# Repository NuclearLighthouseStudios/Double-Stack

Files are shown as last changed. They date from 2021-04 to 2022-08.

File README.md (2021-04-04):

# Double Stack Distortion

These are the KiCAD schematics and board layout filed for my Double Stack Distortion pedal.  
If you just want the Gerber files or a PDF of the schematic check out the releases tab for downloads.

This PCB should be easily manufacturable with most online PCB houses by just uploading the gerber files.

This board is designed to be used with my Switchboard Pedal IO PCB which you can find [here](https://github.com/NuclearLighthouseStudios/Switchboard).

## BOM

| Reference | Quantity | Value  | Description |
| :--- | ---: | -----: | :--- |
| C1 C7 C8 | 3 | 100n | WIMA MKS2 63V |
| C2 C4 C5 | 3 | 470n | WIMA MKS2 50V |
| C3 C6 C10 | 3 | 1µ | WIMA MKS2 50V |
| C9 | 1 | 1n | WIMA FKP2 63V |
| D1 D2 D3 D4 | 4 | 1N4148 | DO-35 Diode |
| J1 | 1 | | Pin Header, 6 pins, 2.54mm spacing |
| J2 | 1 | | DC Barrel Jack with internal switch |
| Q1 Q2 Q3 Q4 | 4 | BC547B | 0.1A Ic, 45V Vce, Small Signal NPN Transistor, TO-92 |
| R1 R2 R11 R12 | 4 | 1M | Metal film resistor 1%, DIN 0207 |
| R10 | 1 | 390k | Metal film resistor 1%, DIN 0207 |
| R3 R7 R9 R13  | 4 | 10k | Metal film resistor 1%, DIN 0207 |
| R4 | 1 | 4.7k | Metal film resistor 1%, DIN 0207 |
| R5 R8 | 2 | 100k | Metal film resistor 1%, DIN 0207 |
| R6 R14 | 2 | 39k | Metal film resistor 1%, DIN 0207 |
| RV1 RV2 | 2 | 100k | Alps RK09K1130C94 Potentiometer |

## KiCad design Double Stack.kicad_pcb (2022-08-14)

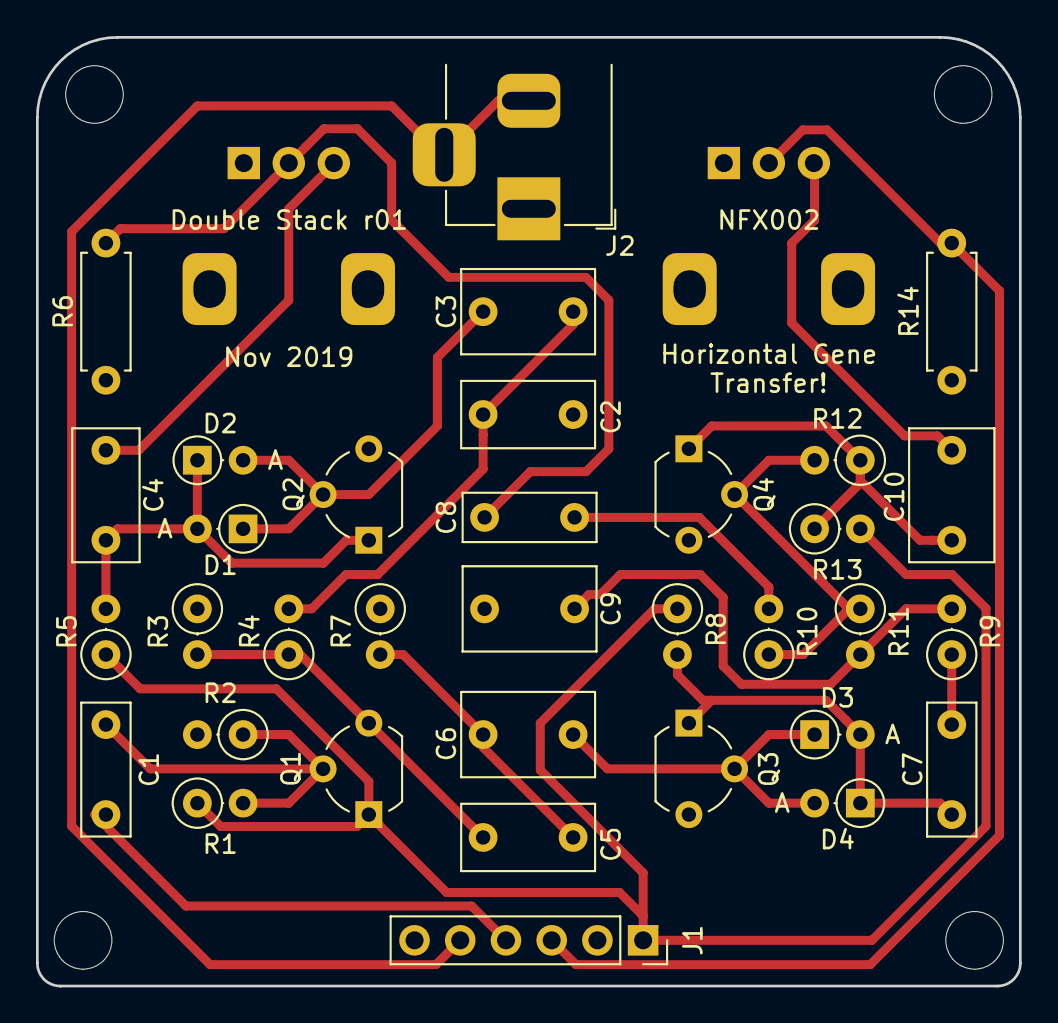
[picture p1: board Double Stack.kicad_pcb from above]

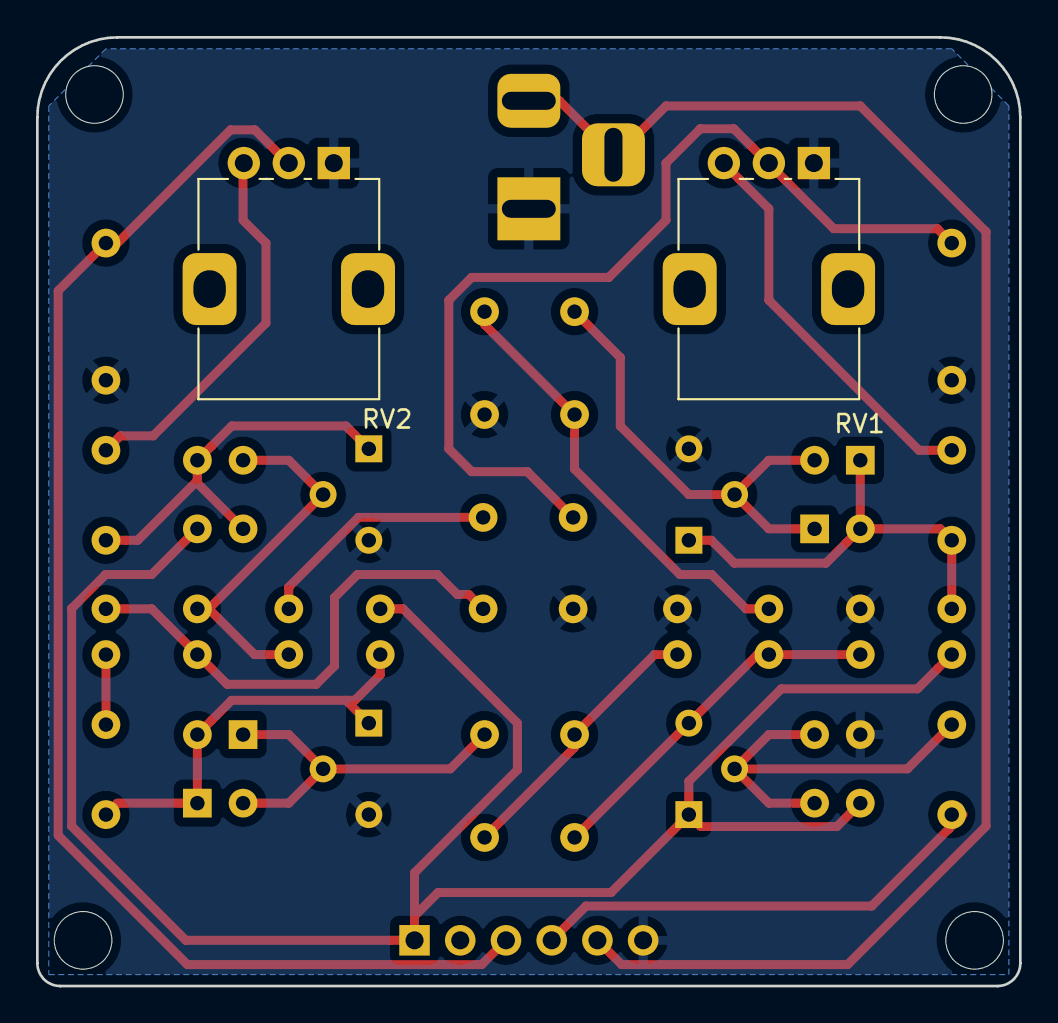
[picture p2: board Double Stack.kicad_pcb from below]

Board: 2 copper layers, 54.6 x 52.7 mm, 36 parts (2 on the bottom side), 21 nets.

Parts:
C1, C7, C8: 100n; C_Rect_L7.2mm_W2.5mm_P5.00mm_FKS2_FKP2_MKS2_MKP2
C2, C4, C5: 470n; C_Rect_L7.2mm_W3.5mm_P5.00mm_FKS2_FKP2_MKS2_MKP2
C3, C6, C10: 1µ; C_Rect_L7.2mm_W4.5mm_P5.00mm_FKS2_FKP2_MKS2_MKP2
C9: 1n; C_Rect_L7.2mm_W4.5mm_P5.00mm_FKS2_FKP2_MKS2_MKP2
D1, D2, D3, D4: 1N4148; D_DO-35_SOD27_P2.54mm_Vertical_AnodeUp
J1: Conn_01x06_Male; PinSocket_1x06_P2.54mm_Vertical
J2: Barrel_Jack_Switch; BarrelJack_Horizontal_Short
Q1, Q2, Q3, Q4: BC547; TO-92_Wide
R1, R2, R11, R12: 1M; R_Axial_DIN0207_L6.3mm_D2.5mm_P2.54mm_Vertical
R3, R7, R9, R13: 10k; R_Axial_DIN0207_L6.3mm_D2.5mm_P2.54mm_Vertical
R4: 4.7k; R_Axial_DIN0207_L6.3mm_D2.5mm_P2.54mm_Vertical
R5, R8: 100k; R_Axial_DIN0207_L6.3mm_D2.5mm_P2.54mm_Vertical
R6, R14: 39k; R_Axial_DIN0207_L6.3mm_D2.5mm_P7.62mm_Horizontal
R10: 390k; R_Axial_DIN0207_L6.3mm_D2.5mm_P2.54mm_Vertical
RV1, RV2: 100k; Potentiometer_Alps_RK09K_Single_Vertical

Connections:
+9V: J1.5, J2.2, J2.3
+9VA: J1.1, Q1.1 (C), R1.1, R5.1, R8.1, R13.2
BuffOut: C5.2, Q1.3 (E), R3.2, R4.1
GND: C2.2, C9.2, J1.6, J2.1, Q2.3 (E), Q3.3 (E), Q4.3 (E), R2.2, R3.1, R6.1, R7.1, R14.1, RV1.1, RV2.1
Input: C1.2, J1.4
LOut: C8.2, R6.2, RV1.2
unnamed: C1.1, Q1.2 (B), R1.2, R2.1
unnamed: C2.1, C3.2, R4.2
unnamed: C3.1, D1.1 (K), D2.2 (A), Q2.2 (B)
unnamed: C4.1, RV1.3
unnamed: C4.2, D1.2 (A), D2.1 (K), Q2.1 (C), R5.2
unnamed: C5.1, C6.2, R7.2
unnamed: C6.1, D3.1 (K), D4.2 (A), Q3.2 (B)
unnamed: C7.1, R9.1
unnamed: C7.2, D3.2 (A), D4.1 (K), Q3.1 (C), R8.2
unnamed: C8.1, R10.2
unnamed: C9.1, R9.2, R11.2
unnamed: C10.1, RV2.3
unnamed: C10.2, Q4.1 (C), R12.1, R13.1
unnamed: Q4.2 (B), R10.1, R11.1, R12.2
Output: J1.3, R14.2, RV2.2

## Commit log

2020-12-31 Fix capacitor types and voltages
2021-04-04 Fix C9 voltage rating in BOM
2022-08-14 Migrate to KiCAD 6
    [Double Stack.kicad_pcb, Double Stack.kicad_sch, Double Stack.sch]

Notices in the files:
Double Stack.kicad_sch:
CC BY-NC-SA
